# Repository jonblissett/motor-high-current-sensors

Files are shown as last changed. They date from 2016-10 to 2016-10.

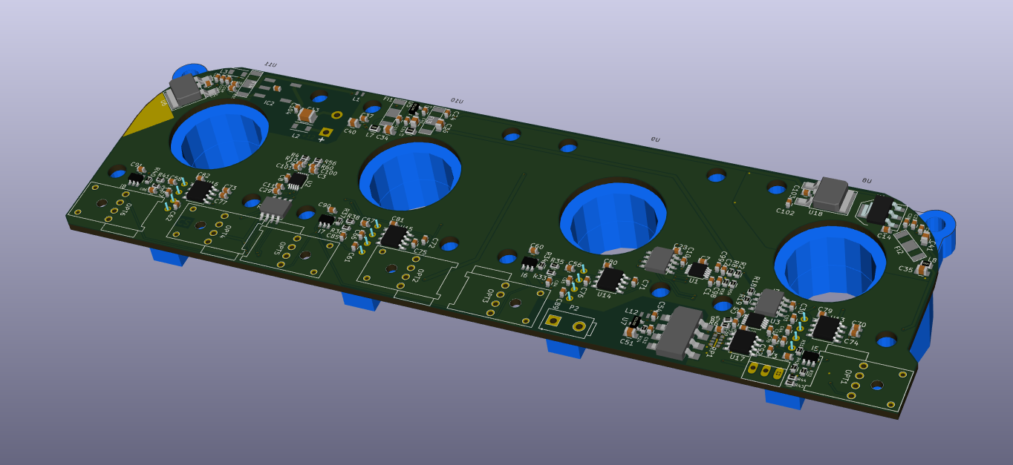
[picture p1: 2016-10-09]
CurrentSensorPCB_V4_140716.png

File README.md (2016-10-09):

# motor-high-current-sensors
Design for a quadruple current sensing board using the LEM HTFS series current sensors, for 200-800A providing 14-bit digital outputs with optical signalling. Designed for sensing 3-phase and DC-bus current on electric vehicles and tested on a racing electric motorcycle.

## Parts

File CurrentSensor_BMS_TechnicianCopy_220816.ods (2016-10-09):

Generated Date | 22/08/2016 16
Title | Bike_3ph_IV_sensor
Company | University of Nottingham
Revision | 2
Date Issue | Not Set
Reference | Value | Library Ref
C55 | 47n | C
C34 | 10u | device
C37 | 10n | C
C40 | 4u7 | C
C16 | 100n | C
U8 | HTFS800 | HTFS800
C59 | 47n | C
C13 | 22u | device
C56 | 47n | C
U9 | HTFS800 | HTFS800
C60 | 47n | C
C57 | 47n | C
U10 | HTFS800 | HTFS800
C61 | 47n | C
U2 | LTC1407-1 | LTC1407
C8 | 10u | C
C11 | 10u | C
I1 | DS90LV028A | DS9637A
R15 | 330 | R
R14 | 330 | R
C24 | 1u | C
C36 | 10u | device
C39 | 10n | C
C42 | 4u7 | C
C27 | 1n | C
C64 | 4n7 | C
U1 | LTC1407-1 | LTC1407
C7 | 10u | C
C10 | 10u | C
FI1 | NFE61P | EMI_FILTER
FI3 | NFE61P | EMI_FILTER
R1 | 3.6k | R
C1 | 5.1n | C
I2 | DS90LV028A | DS9637A
R17 | 330 | R
R16 | 330 | R
I4 | DS90LV027A | DS90LV027A
U12 | ACPL-C870 | ACPL-C870
RP1 | R_PACK4 | R_PACK4
C68 | 1n | C
C69 | 1n | C
C78 | 47n | C
C63 | 47n | C
C52 | 10n | C
R24 | 158 | R
R20 | 100k | R
C54 | 1u | C
C43 | 100n | C
D2 | 3.3V | ZENER
L12 | 10uH | INDUCTOR_SMALL
C58 | 47n | C
U17 | OPA2350 | LM358-RESCUE-CurrentSensorPCB_line
U11 | HTFS400 | HTFS800
C62 | 47n | C
U3 | LTC1407 | LTC1407
C9 | 10u | C
C12 | 10u | C
R5 | 51 | R
C5 | 5.1n | C
R6 | 51 | R
R19 | 330 | R
R18 | 330 | R
C6 | 5.1n | C
C97 | 47n | C
R49 | DNP | R
R50 | DNP | R
C96 | 47n | C
R52 | 0R | R
R51 | DNP | R
C22 | 10u | C
C33 | 10u | C
R13 | 4k7 | R
P1 | CONN_01X02 | CONN_01X02
P3 | CONN_01X03 | CONN_01X03
R48 | DNP | R
R47 | DNP | R
C35 | 10u | device
C38 | 10n | C
C41 | 4u7 | C
C26 | 1n | C
FI2 | NFE61P | EMI_FILTER
D3 | 3.3V | ZENER
P2 | CONN_01X02 | CONN_01X02
U4 | LD1117S33TR | LD1117S50TR
U6 | MC78M05CDT | MC78M05CDT
U7 | MCP1702T-500 | APE8865N-33-HF-3
R21 | 100k | R
R22 | 100k | R
R23 | 100k | R
L6 | 1uH | INDUCTOR_SMALL
OPT3 | AFBR-1634Z | AFBR-1634Z
C19 | 100n | C
C21 | 10u | C
C32 | 10u | C
R12 | 4k7 | R
L5 | 1uH | INDUCTOR_SMALL
OPT2 | AFBR-1634Z | AFBR-1634Z
C18 | 100n | C
C20 | 10u | C
C31 | 10u | C
R11 | 4k7 | R
L4 | 1uH | INDUCTOR_SMALL
OPT1 | AFBR-1634Z | AFBR-1634Z
C17 | 100n | C
OPT5 | AFBR-26x | AFBR-26x
C48 | 10u | C
C45 | 10u | C
L11 | 1uH | INDUCTOR_SMALL
C50 | 100n | C
OPT4 | AFBR-26x | AFBR-26x
C47 | 10u | C
C44 | 10u | C
L10 | 1uH | INDUCTOR_SMALL
C49 | 100n | C
C88 | 100n | C
C83 | 47n | C
R30 | 1k6 | R
R31 | 910 | R
R32 | 270 | R
R46 | 4k7 | R
C94 | 10u | C
C95 | 10u | C
R45 | DNP | R
L13 | 1uH | INDUCTOR_SMALL
C93 | 100n | C
OPT6 | AFBR-1634Z | AFBR-1634Z
C46 | 1n | C
U5 | MCP1700T-330 | APE8865N-33-HF-3
C15 | 100n | C
C14 | 100n | C
C23 | 1u | C
C25 | 1u | C
I5 | ADCMP671 | ADCMP671
C89 | 100n | C
C84 | 47n | C
R33 | 1k6 | R
R34 | 910 | R
R35 | 270 | R
I6 | ADCMP671 | ADCMP671
C90 | 100n | C
C85 | 47n | C
R36 | 1k6 | R
R37 | 910 | R
R38 | 270 | R
I7 | ADCMP671 | ADCMP671
C91 | 100n | C
C86 | 47n | C
R39 | 1k6 | R
R40 | 910 | R
R41 | 270 | R
I8 | ADCMP671 | ADCMP671
C92 | 100n | C
C87 | 47n | C
R42 | DNP | R
R43 | DNP | R
R44 | DNP | R
I9 | ADCMP671 | ADCMP671
C53 | 100n | C
C29 | 100n | C
C28 | 100n | C
C30 | 100n | C
I3 | DS90LV028A | DS9637A
U13 | MAX7480 | MAX7480
C70 | 27p | C
C74 | 100n | C
R7 | 6.8k | R
C79 | 100n | C
C65 | 4n7 | C
U14 | MAX7480 | MAX7480
C71 | 27p | C
C75 | 100n | C
C80 | 100n | C
C66 | 4n7 | C
U15 | MAX7480 | MAX7480
C72 | 27p | C
C76 | 100n | C
C81 | 100n | C
C67 | 4n7 | C
U16 | MAX7480 | MAX7480
C73 | 27p | C
C77 | 100n | C
C82 | 100n | C
R2 | 3.6k | R
C2 | 5.1n | C
R8 | 6.8k | R
R3 | 3.6k | R
C3 | 5.1n | C
R9 | 6.8k | R
R4 | 3.6k | R
C4 | 5.1n | C
R10 | 6.8k | R
L7 | ? | INDUCTOR_SMALL
L8 | ? | INDUCTOR_SMALL
L9 | ? | INDUCTOR_SMALL
R53 | 270 | R
IC1 | Murata_MTU1 | Murata_MTU1
R55 | 3.6k | R
R59 | 6.8k | R
C99 | 5.1n | C
R54 | 3.6k | R
R58 | 6.8k | R
C98 | 5.1n | C
U18 | MC78M05CDT | MC78M05CDT
C103 | 1u | C
C102 | 100n | C
L1 | INDUCTOR_SMALL | INDUCTOR_SMALL
R56 | 3.6k | R
R60 | 6.8k | R
C100 | 5.1n | C
R57 | 3.6k | R
R61 | 6.8k | R
C101 | 5.1n | C
C51 | 4u7 | C
IC2 | Murata_MTU1 | Murata_MTU1
L3 | 10uH | INDUCTOR_SMALL
C104 | 1n | C
FI4 | NFE61P | EMI_FILTER
C108 | 1n | C
C106 | 1n | C
C105 | 1u | C
C107 | 1u | C
L2 | 10uH | INDUCTOR_SMALL

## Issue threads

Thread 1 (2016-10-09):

Noise isolation

jonblissett, 2016-10-09:
Found during testing that excessive noise is present when the board is supplied from the vehicles main 12V battery. The noise is greatly reduced by isolating the supply, using an additional battery or DC-DC converter. The power rating of the DC-DC converter in the design is insufficient, so should be changed and is untested.

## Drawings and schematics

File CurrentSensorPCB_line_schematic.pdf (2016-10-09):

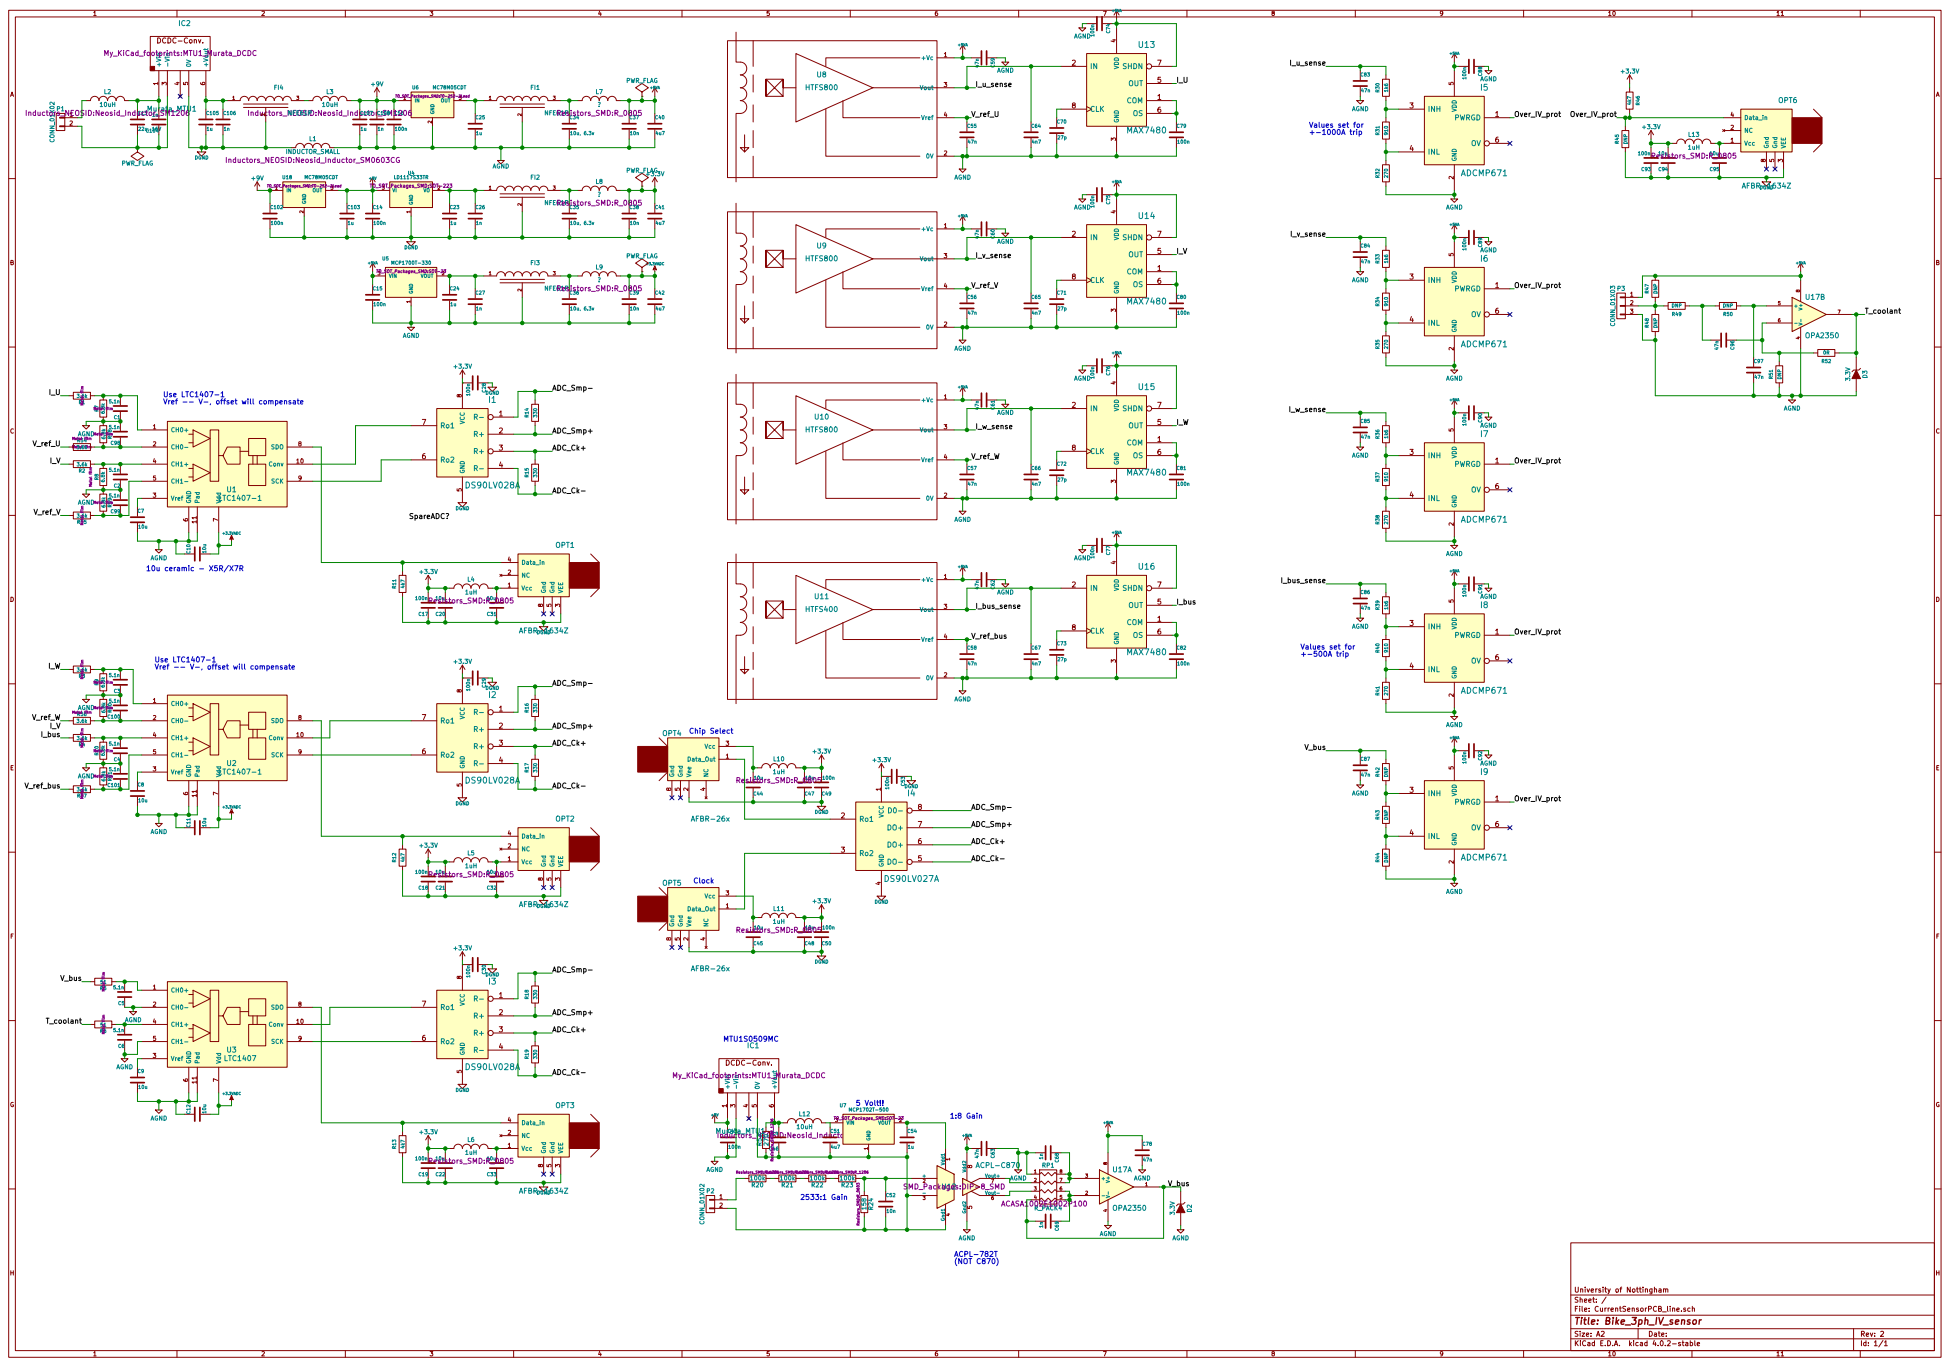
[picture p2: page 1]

4 OUT 5 OS 6 SHDN 7 CLK 8 U13

Values set for +-1000A trip

4 OUT 5 OS 6 SHDN 7 CLK 8 U14

4 OUT 5 OS 6 SHDN 7 CLK 8 U15

Vref -- V-, offset will compensate
5.1n R8 6.8k Metal film R3

7 SDO 8 SCK 9 Conv 10 Pad 11 U1

4 OUT 5 OS 6 SHDN 7 CLK 8 U16

Values set for +-500A trip

Use LTC1407-1

7 SDO 8 SCK 9 Conv 10 Pad 11 U2

7 SDO 8 SCK 9 Conv 10 Pad 11 U3

File: CurrentSensorPCB_line.sch Sheet: / University of Nottingham

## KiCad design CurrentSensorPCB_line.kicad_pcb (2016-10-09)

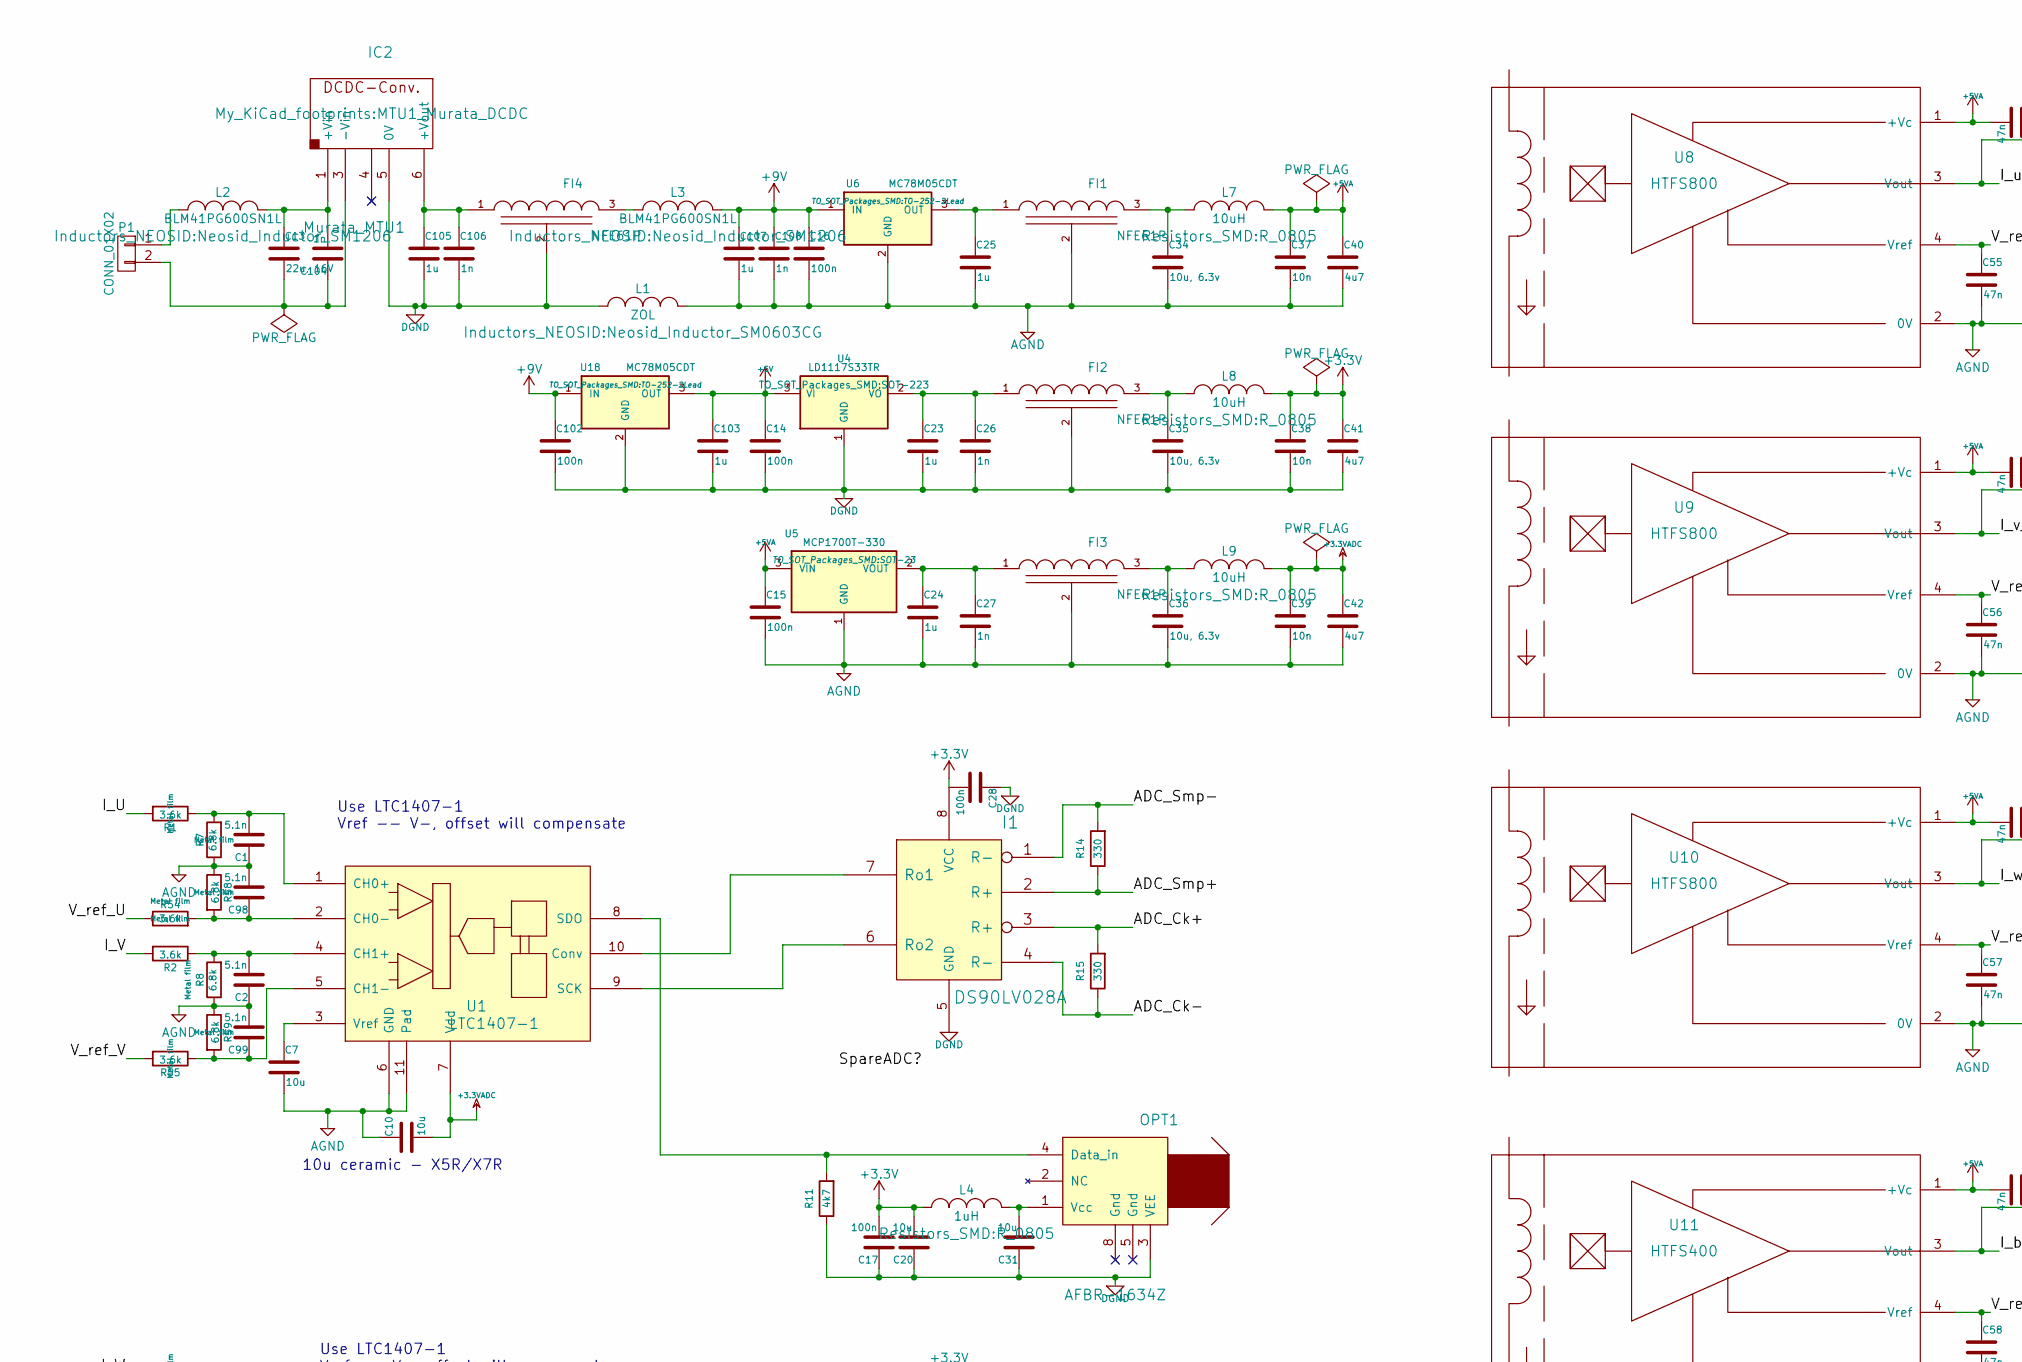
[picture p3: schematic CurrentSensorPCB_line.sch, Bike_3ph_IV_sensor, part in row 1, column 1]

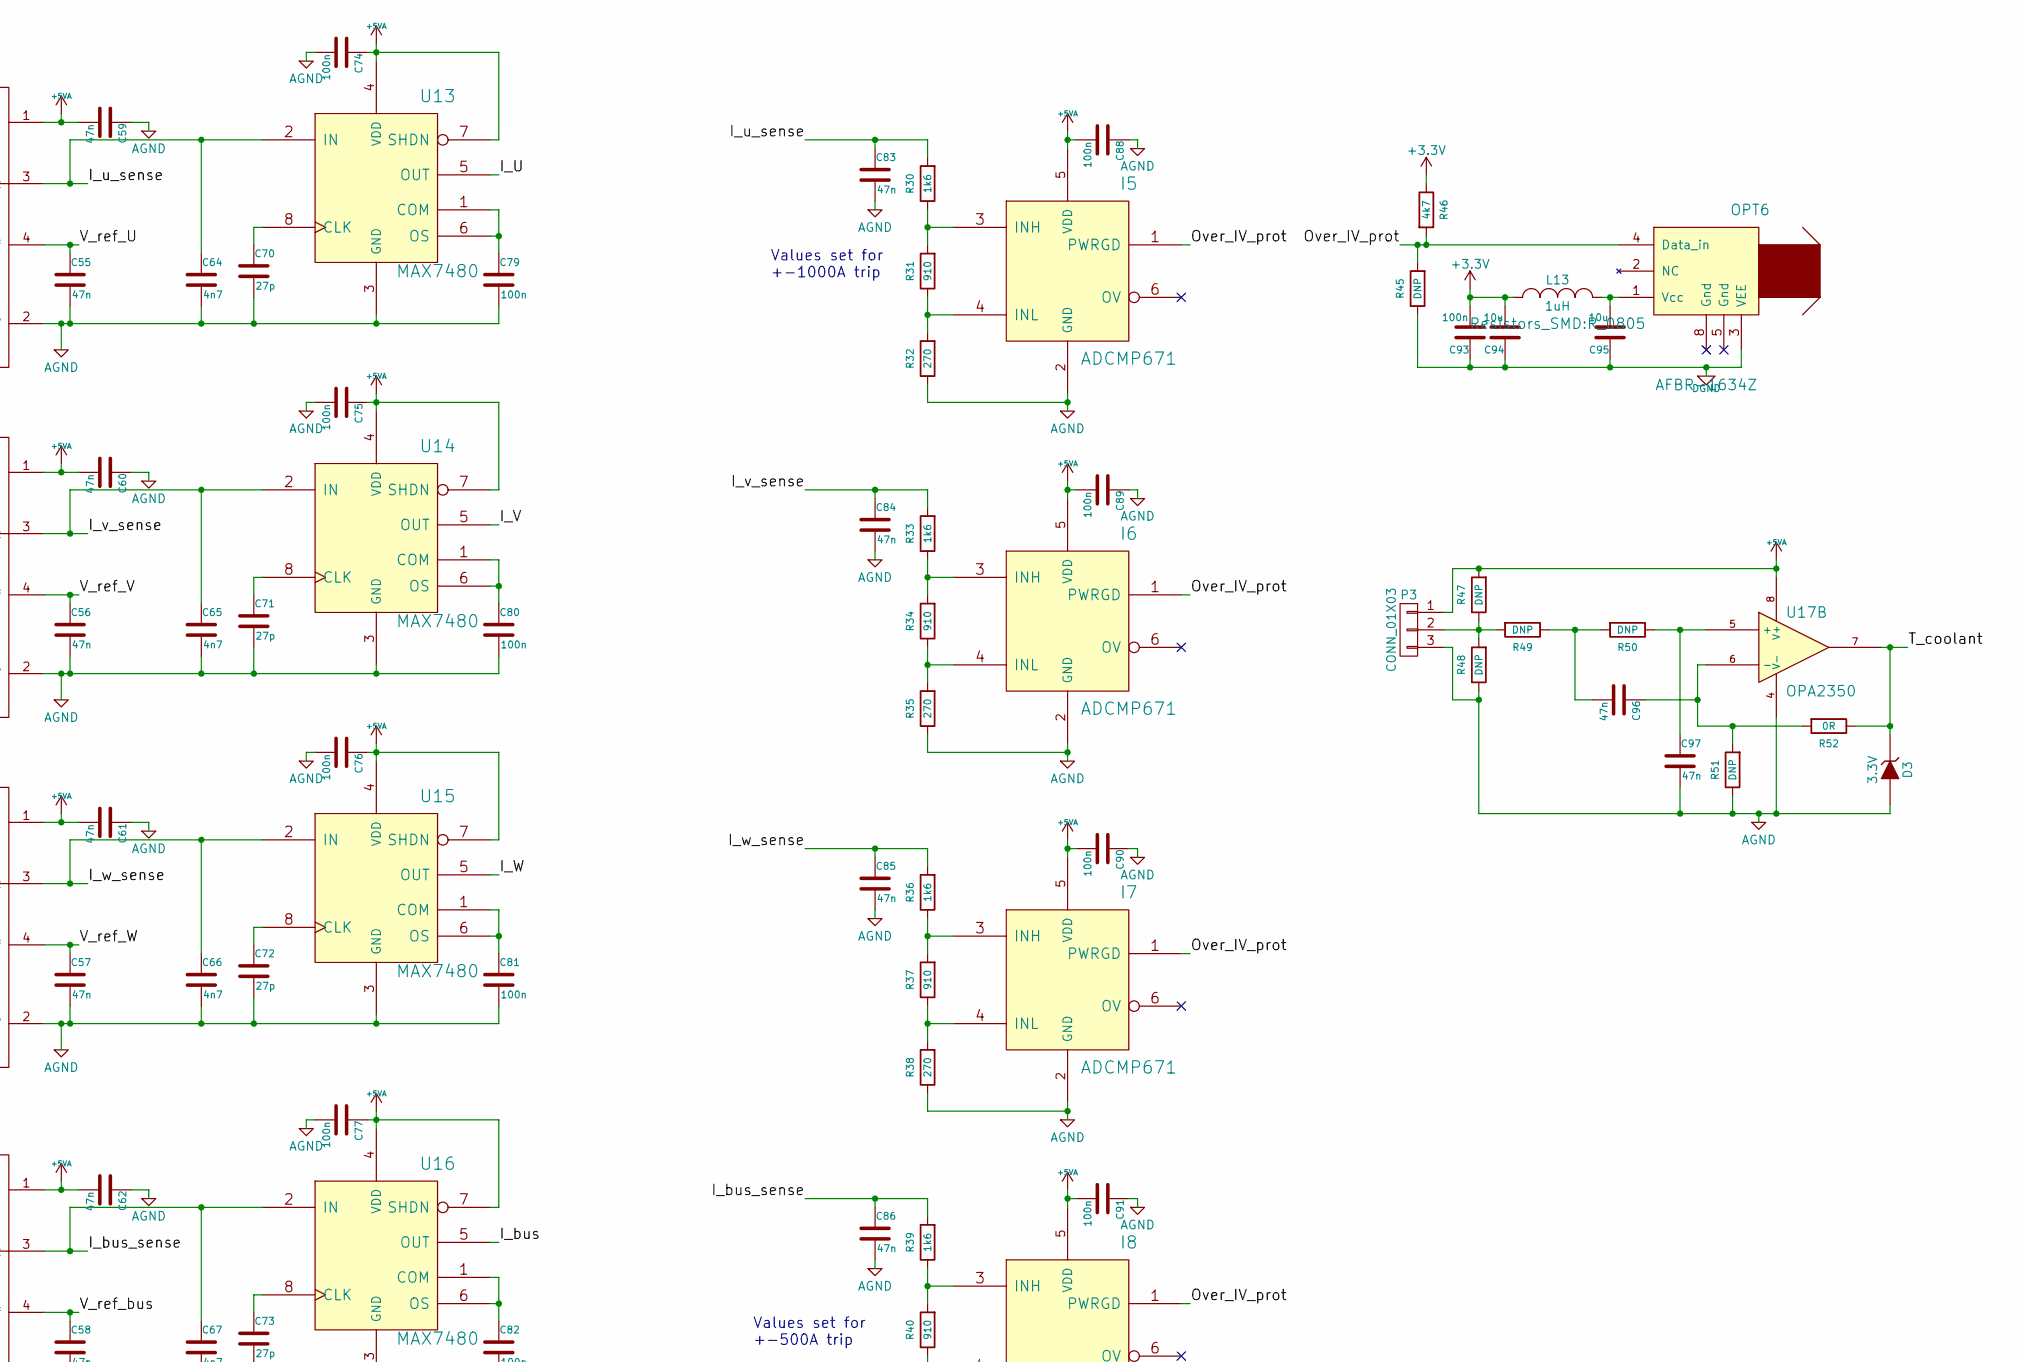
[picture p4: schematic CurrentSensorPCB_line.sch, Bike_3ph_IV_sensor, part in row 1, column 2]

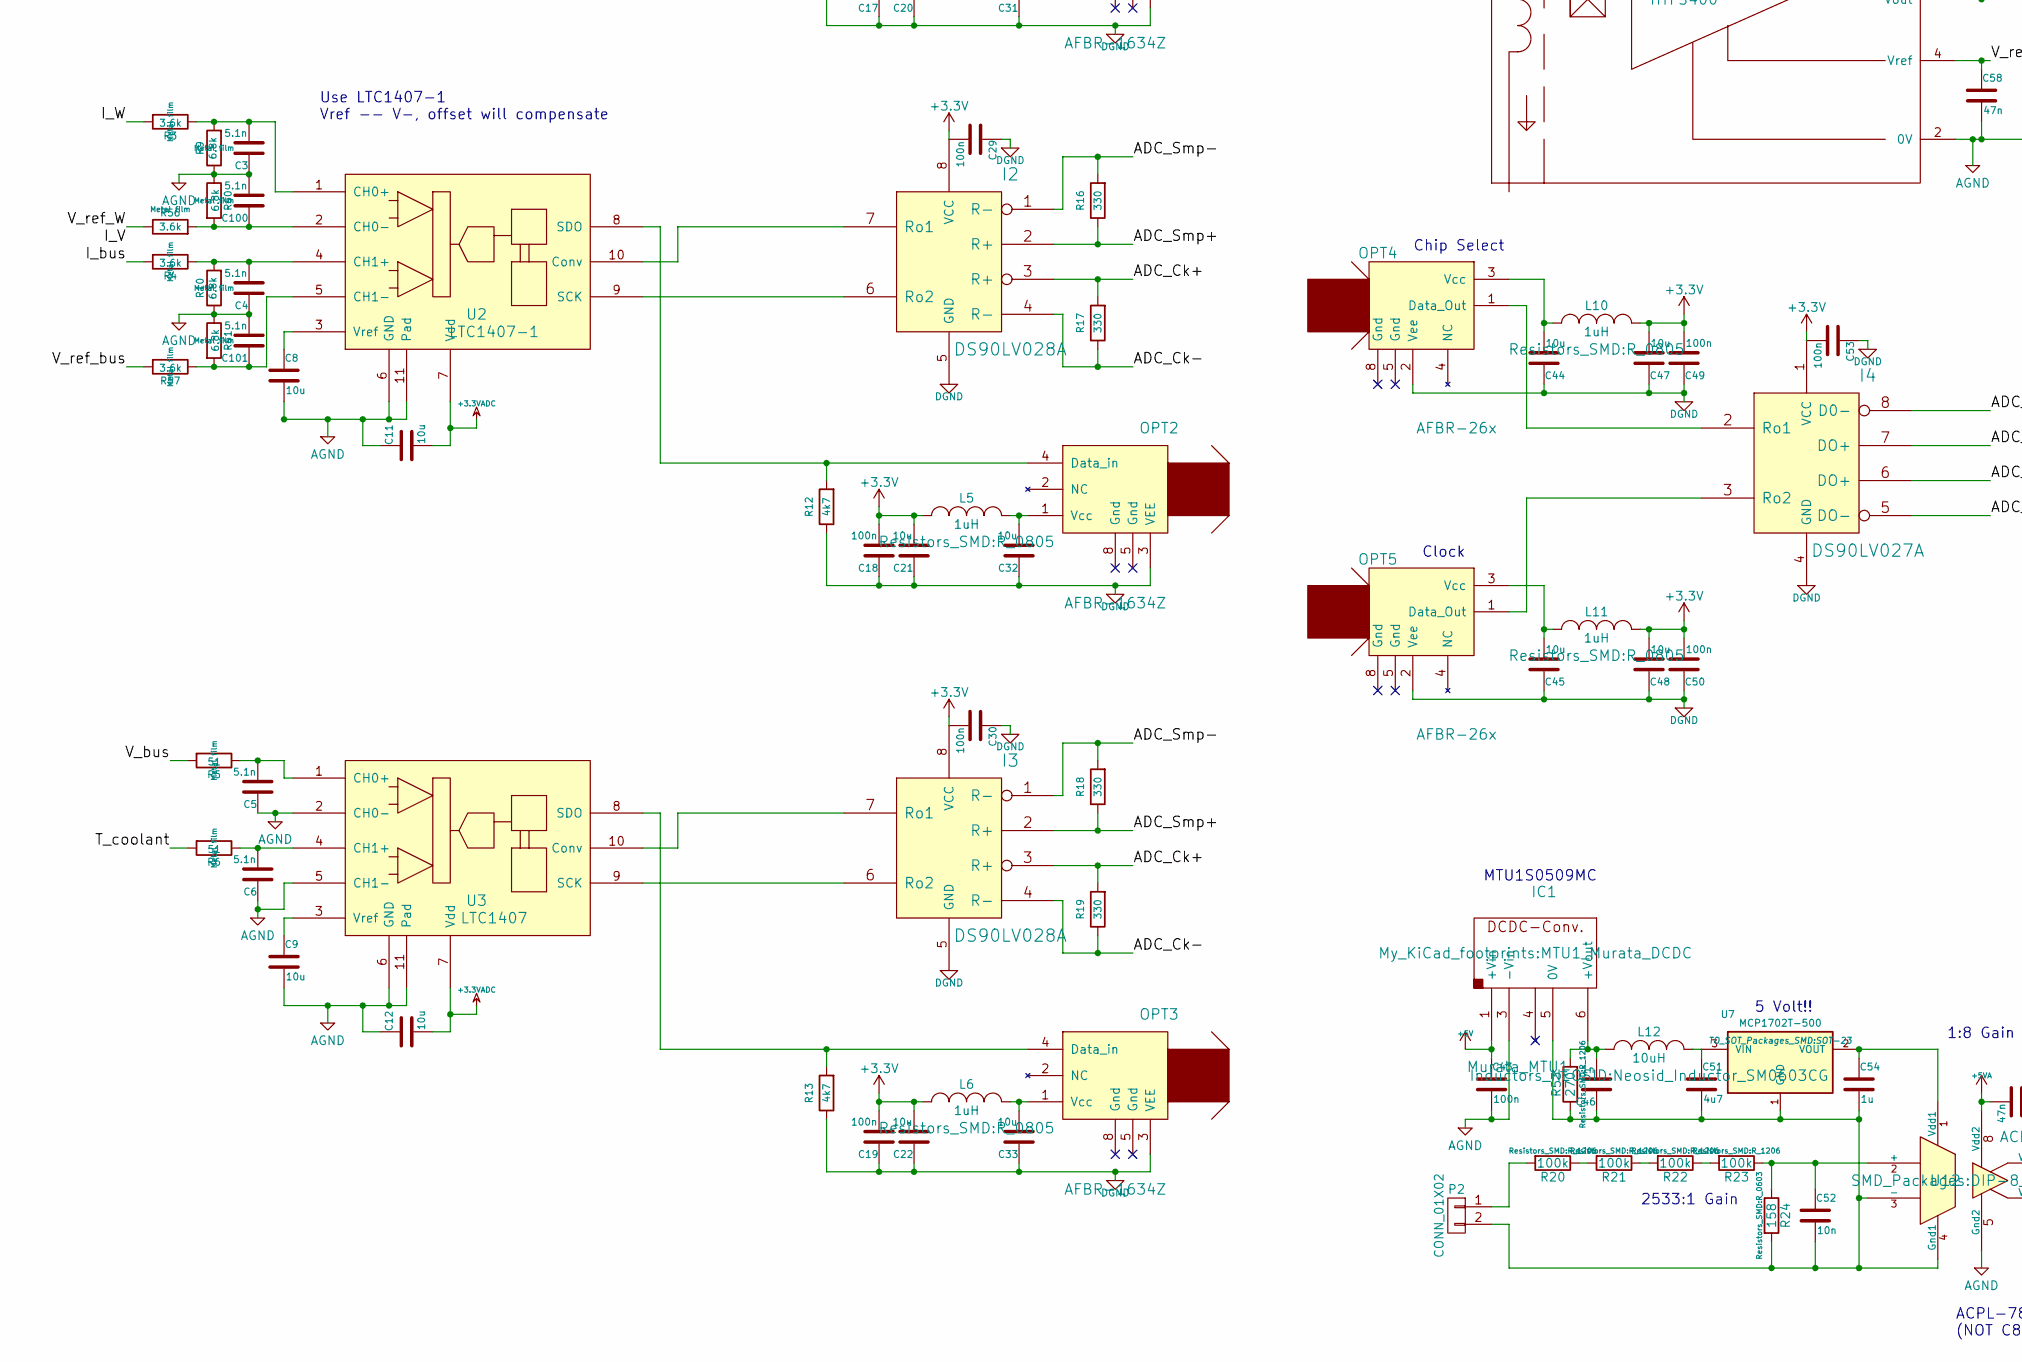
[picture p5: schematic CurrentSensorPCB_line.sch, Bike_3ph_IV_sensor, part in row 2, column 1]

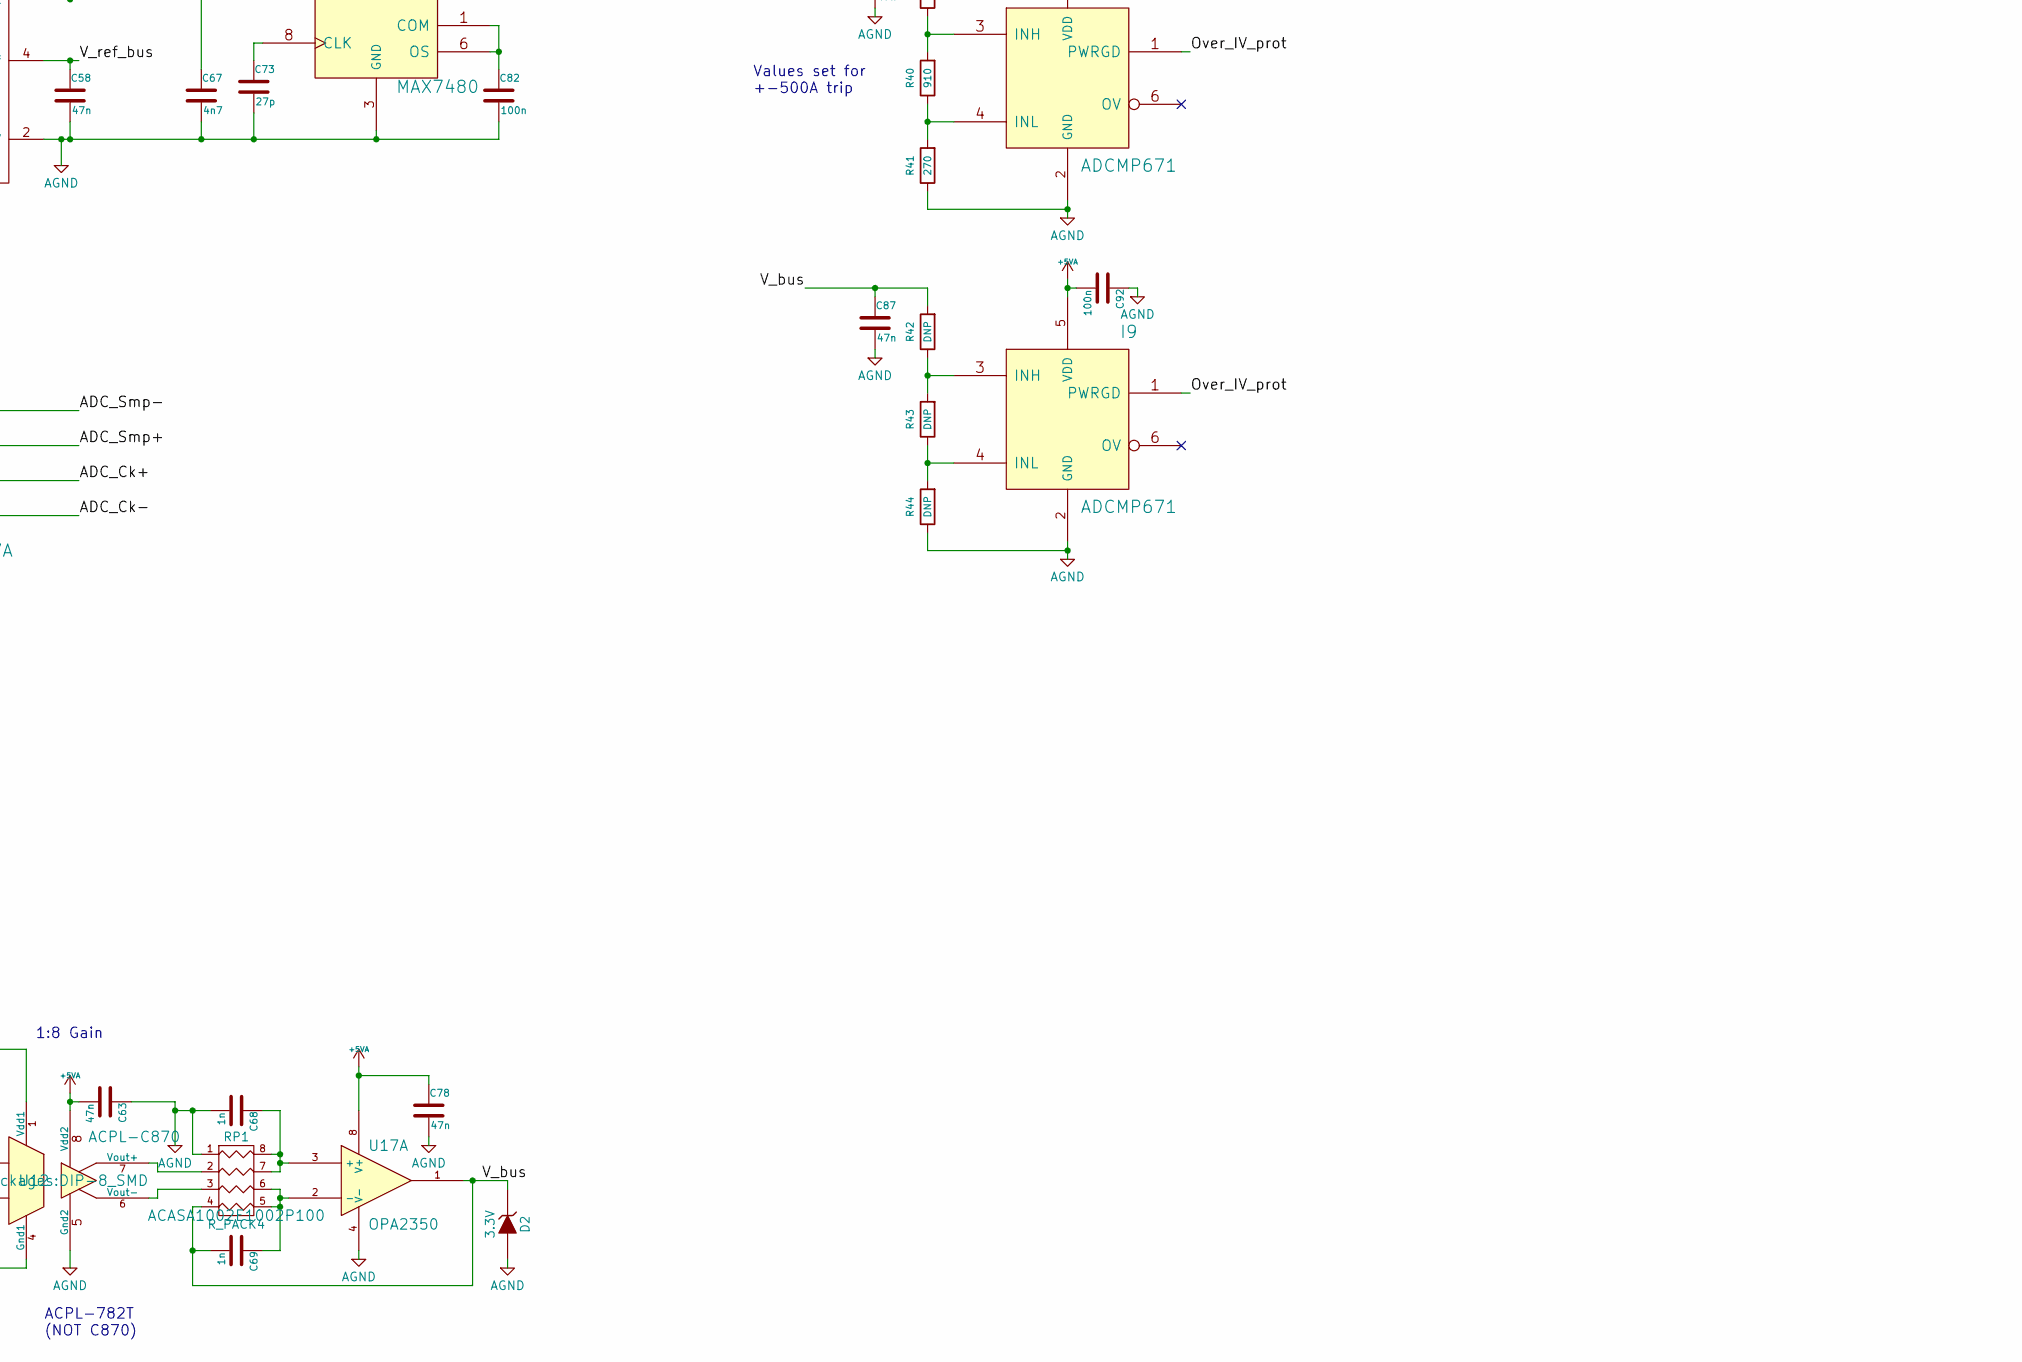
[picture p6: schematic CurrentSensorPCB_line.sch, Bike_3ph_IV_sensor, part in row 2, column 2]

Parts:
C1, C2, C3, C4, C5, C6, C98, C99, C100, C101: 5.1n; C_0603
C7, C8, C9, C10, C11, C12, C20, C21, C22, C31, C32, C33, C44, C45, C47, C48, C94, C95: 10u; C_0603
C13: 22u, 16V; C_1210
C14, C15, C16, C17, C18, C19, C28, C29, C30, C43, C49, C50, C53, C74, C75, C76, C77, C79, C80, C81, C82, C88, C89, C90, C91, C92, C93, C102: 100n; C_0603
C23, C24, C25, C54, C103, C105, C107: 1u; C_0603
C26, C27, C46, C68, C69, C104, C106, C108: 1n; C_0603
C34, C35, C36: 10u, 6.3v; C_0805
C37, C38, C39, C52: 10n; C_0603
C40, C41, C42, C51: 4u7; C_0805
C55, C56, C57, C58, C59, C60, C61, C62, C63, C78, C83, C84, C85, C86, C87, C96, C97: 47n; C_0603
C64, C65, C66, C67: 4n7; C_0603
C70, C71, C72, C73: 27p; C_0603
D2, D3: 3.3V; SOD-523
FI1, FI2, FI3, FI4: NFE61P; EMI_Filter_murata
I1, I2, I3: DS90LV028A; SOIC-8-N
I4: DS90LV027A; SOIC-8-N
I5, I6, I7, I8, I9: ADCMP671; TSOT-6-MK06A
IC1, IC2: Murata_MTU1; MTU1_Murata_DCDC
L1: ZOL; Neosid_Inductor_SM0603CG
L2, L3: BLM41PG600SN1L; Neosid_Inductor_SM1206
L4, L5, L6, L10, L11, L13: 1uH; R_0805
L7, L8, L9: 10uH; R_0805
L12: 10uH; Neosid_Inductor_SM0603CG
OPT1, OPT2, OPT3, OPT6: AFBR-1634Z; HFBR-xx3xZ
OPT4, OPT5: AFBR-26x; HFBR-xx3xZ
P1, P2: CONN_01X02; Connector_Header_2Way_39-29-3026
P3: CONN_01X03; PINHEAD1-3
R1, R2, R3, R4, R54, R55, R56, R57: 3.6k; R_0603
R5, R6: 51; R_0603
R7, R8, R9, R10, R58, R59, R60, R61: 6.8k; R_0603
R11, R12, R13, R46: 4k7; R_0603
R14, R15, R16, R17, R18, R19: 330; R_0603
R20, R21, R22, R23: 100k; R_1206
R24: 158; R_0603
R30, R33, R36, R39: 1k6; R_0603
R31, R34, R37, R40: 910; R_0603
R32, R35, R38, R41: 270; R_0603
R42, R43, R44, R45, R47, R48, R49, R50, R51: DNP; R_0603
R52: 0R; R_0603
R53: 270; R_1206
RP1: R_PACK4; ACAS0612
U1, U2: LTC1407-1; MSOP-10-1EP_3x3mm_Pitch0.5mm
U3: LTC1407; MSOP-10-1EP_3x3mm_Pitch0.5mm
U4: LD1117S33TR; SOT-223
U5: MCP1700T-330; SOT-23
U6, U18: MC78M05CDT; TO-252-2Lead
U7: MCP1702T-500; SOT-23
U8, U9, U10: HTFS800; HTFS-Series_LEM-HallEffektCurrentTransducer
U11: HTFS400; HTFS-Series_LEM-HallEffektCurrentTransducer
U12: ACPL-C870; DIP-8_SMD
U13, U14, U15, U16: MAX7480; SOIC-8_3.9x4.9mm_Pitch1.27mm
U17: OPA2350; SOIC-8_3.9x4.9mm_Pitch1.27mm

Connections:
+3.3VADC: C10.2, C11.2, C12.2, C39.1, C42.1, L9.2, U1.7 (Vdd), U2.7 (Vdd), U3.7 (Vdd)
+3V3: C17.2, C18.2, C19.2, C20.2, C21.2, C22.2, C28.2, C29.2, C30.2, C38.1, C41.1, C47.2, C48.2, C49.2, C50.2, C53.2, C93.2, C94.2, I1.8 (VCC), I2.8 (VCC), I3.8 (VCC), I4.1 (VCC), L4.1, L5.1, L6.1, L8.2, L10.1, L11.1, L13.1, R46.1
+5V: C14.1, C43.1, C103.1, IC1.1 (+Vin), U4.3 (VI), U18.3 (OUT)
+5VA: C15.1, C37.1, C40.1, C59.2, C60.2, C61.2, C62.2, C63.2, C74.1, C75.1, C76.1, C77.1, C78.1, C88.2, C89.2, C90.2, C91.2, C92.2, I5.5 (VDD), I6.5 (VDD), I7.5 (VDD), I8.5 (VDD), I9.5 (VDD), L7.2, P3.1, R47.2, U5.3 (VIN), U8.1 (+Vc), U9.1 (+Vc), U10.1 (+Vc), U11.1 (+Vc), U12.8 (Vdd2), U13.4 (VDD), U13.7 (SHDN), U14.4 (VDD), U14.7 (SHDN), U15.4 (VDD), U15.7 (SHDN), U16.4 (VDD), U16.7 (SHDN), U17.8 (V+)
+9V: C16.1, C102.1, C107.1, C108.1, L3.2, U6.1 (IN), U18.1 (IN)
/ADC_Ck+: I1.3 (R+), I2.3 (R+), I3.3 (R+), I4.6 (DO+), R15.2, R17.2, R19.2
/ADC_Ck-: I1.4 (R-), I2.4 (R-), I3.4 (R-), I4.5 (DO-), R15.1, R17.1, R19.1
/ADC_Smp+: I1.2 (R+), I2.2 (R+), I3.2 (R+), I4.7 (DO+), R14.1, R16.1, R18.1
/ADC_Smp-: I1.1 (R-), I2.1 (R-), I3.1 (R-), I4.8 (D0-), R14.2, R16.2, R18.2
/I_U: R1.2, U13.5 (OUT)
/I_V: R2.2, U14.5 (OUT)
/I_W: R3.2, U15.5 (OUT)
/I_bus: R4.2, U16.5 (OUT)
/I_bus_sense: C67.1, C86.1, R39.2, U11.3 (Vout), U16.2 (IN)
/I_u_sense: C64.1, C83.1, R30.2, U8.3 (Vout), U13.2 (IN)
/I_v_sense: C65.1, C84.1, R33.2, U9.3 (Vout), U14.2 (IN)
/I_w_sense: C66.1, C85.1, R36.2, U10.3 (Vout), U15.2 (IN)
/Over_IV_prot: I5.1 (PWRGD), I6.1 (PWRGD), I7.1 (PWRGD), I8.1 (PWRGD), I9.1 (PWRGD), OPT6.4 (Data_in), R45.2, R46.2
/T_coolant: D3.1 (K), R6.2, R52.1, U17.7
/V_bus: C69.2, C87.1, D2.1 (K), R5.2, R42.2, RP1.4, U17.1
/V_ref_U: C55.1, R54.1, U8.4 (Vref)
/V_ref_V: C56.1, R55.2, U9.4 (Vref)
/V_ref_W: C57.1, R56.1, U10.4 (Vref)
/V_ref_bus: C58.1, R57.2, U11.4 (Vref)
AGND: C1.1, C2.1, C3.1, C4.1, C5.1, C6.1, C7.2, C8.2, C9.2, C10.1, C11.1, C12.1, C15.2, C16.2, C24.2, C25.2, C27.2, C34.2, C36.2, C37.2, C39.2, C40.2, C42.2, C43.2, C55.2, C56.2, C57.2, C58.2, C59.1, C60.1, C61.1, C62.1, C63.1, C64.2, C65.2, C66.2, C67.2, C68.2, C70.2, C71.2, C72.2, C73.2, C74.2, C75.2, C76.2, C77.2, C78.2, C79.2, C80.2, C81.2, C82.2, C83.2, C84.2, C85.2, C86.2, C87.2, C88.1, C89.1, C90.1, C91.1, C92.1, C97.2, C98.2, C99.2, C100.2, C101.2, C107.2, C108.2, D2.2 (A), D3.2 (A), FI1.2 (GND), FI3.2 (GND), I5.2 (GND), I6.2 (GND), I7.2 (GND), I8.2 (GND), I9.2 (GND), IC1.3 (-Vin), L1.2, P3.3, R7.1, R8.1, R9.1, R10.1, R32.1, R35.1, R38.1, R41.1, R44.1, R48.1, R51.1, R58.1, R59.1, R60.1, R61.1, RP1.1, U1.6 (GND), U1.11 (Pad), U2.6 (GND), U2.11 (Pad), U3.2 (CH0-), U3.5 (CH1-), U3.6 (GND), U3.11 (Pad), U5.1 (GND), U6.2 (GND), U8.2 (0V), U9.2 (0V), U10.2 (0V), U11.2 (0V), U12.5 (Gnd2), U13.3 (GND), U14.3 (GND), U15.3 (GND), U16.3 (GND), U17.4 (V-)
DGND: C14.2, C17.1, C18.1, C19.1, C20.1, C21.1, C22.1, C23.2, C26.2, C28.1, C29.1, C30.1, C31.1, C32.1, C33.1, C35.2, C38.2, C41.2, C44.1, C45.1, C47.1, C48.1, C49.1, C50.1, C53.1, C93.1, C94.1, C95.1, C102.2, C103.2, C105.2, C106.2, FI2.2 (GND), FI4.2 (GND), I1.5 (GND), I2.5 (GND), I3.5 (GND), I4.4 (GND), IC2.5 (0V), L1.1, OPT1.3 (VEE), OPT2.3 (VEE), OPT3.3 (VEE), OPT4.2 (Vee), OPT5.2 (Vee), OPT6.3 (VEE), R11.1, R12.1, R13.1, R45.1, U4.1 (GND), U18.2 (GND)
unnamed: C1.2, R1.1, R7.2, U1.1 (CH0+)
unnamed: C2.2, R2.1, R8.2, U1.4 (CH1+)
unnamed: C3.2, R3.1, R9.2, U2.1 (CH0+)
unnamed: C4.2, R4.1, R10.2, U2.4 (CH1+)
unnamed: C5.2, R5.1, U3.1 (CH0+)
unnamed: C6.2, R6.1, U3.4 (CH1+)
unnamed: C7.1, U1.3 (Vref)
unnamed: C8.1, U2.3 (Vref)
unnamed: C9.1, U3.3 (Vref)
unnamed: C23.1, C26.1, FI2.1 (VI), U4.2 (VO)
unnamed: C24.1, C27.1, FI3.1 (VI), U5.2 (VOUT)
unnamed: C25.1, FI1.1 (VI), U6.3 (OUT)
unnamed: C31.2, L4.2, OPT1.1 (Vcc)
unnamed: C32.2, L5.2, OPT2.1 (Vcc)
unnamed: C33.2, L6.2, OPT3.1 (Vcc)
unnamed: C34.1, FI1.3 (VO), L7.1
unnamed: C35.1, FI2.3 (VO), L8.1
unnamed: C36.1, FI3.3 (VO), L9.1
unnamed: C44.2, L10.2, OPT4.3 (Vcc)
unnamed: C45.2, L11.2, OPT5.3 (Vcc)
unnamed: C46.1, C51.2, C52.2, C54.2, IC1.5 (0V), P2.2, R24.2, R53.1, U7.1 (GND), U12.3 (-), U12.4 (Gnd1)
unnamed: C46.2, IC1.6 (+Vout), L12.1, R53.2
unnamed: C51.1, L12.2, U7.3 (VIN)
unnamed: C52.1, R23.1, R24.1, U12.2 (+)
unnamed: C54.1, U7.2 (VOUT), U12.1 (Vdd1)
unnamed: C68.1, RP1.7 (R2), RP1.8 (R1), U17.3 (+)
unnamed: C69.1, RP1.5 (R4), RP1.6 (R3), U17.2 (-)
unnamed: C70.1, U13.8 (CLK)
unnamed: C71.1, U14.8 (CLK)
unnamed: C72.1, U15.8 (CLK)
unnamed: C73.1, U16.8 (CLK)
unnamed: C79.1, U13.1 (COM), U13.6 (OS)
unnamed: C80.1, U14.1 (COM), U14.6 (OS)
unnamed: C81.1, U15.1 (COM), U15.6 (OS)
unnamed: C82.1, U16.1 (COM), U16.6 (OS)
unnamed: C95.2, L13.2, OPT6.1 (Vcc)
unnamed: C96.1, R51.2, R52.2, U17.6 (-)
unnamed: C96.2, R49.1, R50.2
unnamed: C97.1, R50.1, U17.5 (+)
unnamed: C98.1, R54.2, R58.2, U1.2 (CH0-)
unnamed: C99.1, R55.1, R59.2, U1.5 (CH1-)
unnamed: C100.1, R56.2, R60.2, U2.2 (CH0-)
unnamed: C101.1, R57.1, R61.2, U2.5 (CH1-)
unnamed: C13.2, C104.1, IC2.3 (-Vin), P1.2
unnamed: C13.1, C104.2, IC2.1 (+Vin), L2.2
unnamed: C105.1, C106.1, FI4.1 (VI), IC2.6 (+Vout)
unnamed: FI4.3 (VO), L3.1
unnamed: I1.6 (Ro2), U1.9 (SCK)
unnamed: I1.7 (Ro1), U1.10 (Conv)
unnamed: I2.6 (Ro2), U2.9 (SCK)
unnamed: I2.7 (Ro1), U2.10 (Conv)
unnamed: I3.6 (Ro2), U3.9 (SCK)
unnamed: I3.7 (Ro1), U3.10 (Conv)
unnamed: I4.2 (Ro1), OPT4.1 (Data_Out)
unnamed: I4.3 (Ro2), OPT5.1 (Data_Out)
unnamed: I5.3 (INH), R30.1, R31.2
unnamed: I5.4 (INL), R31.1, R32.2
unnamed: I6.3 (INH), R33.1, R34.2
unnamed: I6.4 (INL), R34.1, R35.2
unnamed: I7.3 (INH), R36.1, R37.2
unnamed: I7.4 (INL), R37.1, R38.2
unnamed: I8.3 (INH), R39.1, R40.2
unnamed: I8.4 (INL), R40.1, R41.2
unnamed: I9.3 (INH), R42.1, R43.2
unnamed: I9.4 (INL), R43.1, R44.2
unnamed: L2.1, P1.1
unnamed: OPT1.4 (Data_in), R11.2, U1.8 (SDO)
unnamed: OPT2.4 (Data_in), R12.2, U2.8 (SDO)
unnamed: OPT3.4 (Data_in), R13.2, U3.8 (SDO)
unnamed: P2.1, R20.2
unnamed: P3.2, R47.1, R48.2, R49.2
unnamed: R20.1, R21.2
unnamed: R21.1, R22.2
unnamed: R22.1, R23.2
unnamed: RP1.2, U12.7 (Vout+)
unnamed: RP1.3, U12.6 (Vout-)

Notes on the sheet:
10u ceramic - X5R/X7R
Clock
Chip Select
Use LTC1407-1 Vref -- V-, offset will compensate
5 Volt!!
ACPL-782T (NOT C870)
MTU1S0509MC
1:8 Gain
2533:1 Gain
Values set for +-1000A trip
Values set for +-500A trip

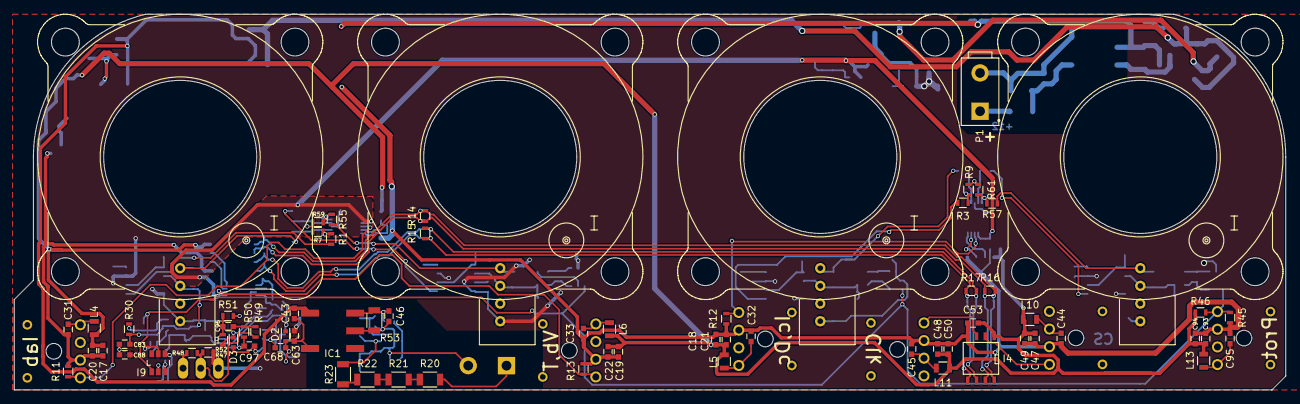
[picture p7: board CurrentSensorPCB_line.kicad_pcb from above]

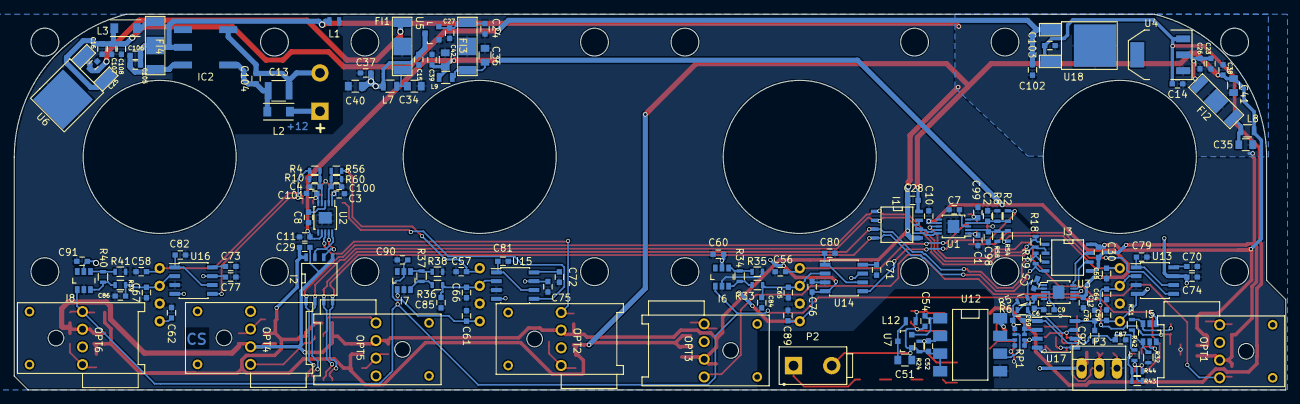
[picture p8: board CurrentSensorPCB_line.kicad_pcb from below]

Board: 2 copper layers, 182.8 x 54.0 mm, 222 parts (150 on the bottom side), 102 nets.
